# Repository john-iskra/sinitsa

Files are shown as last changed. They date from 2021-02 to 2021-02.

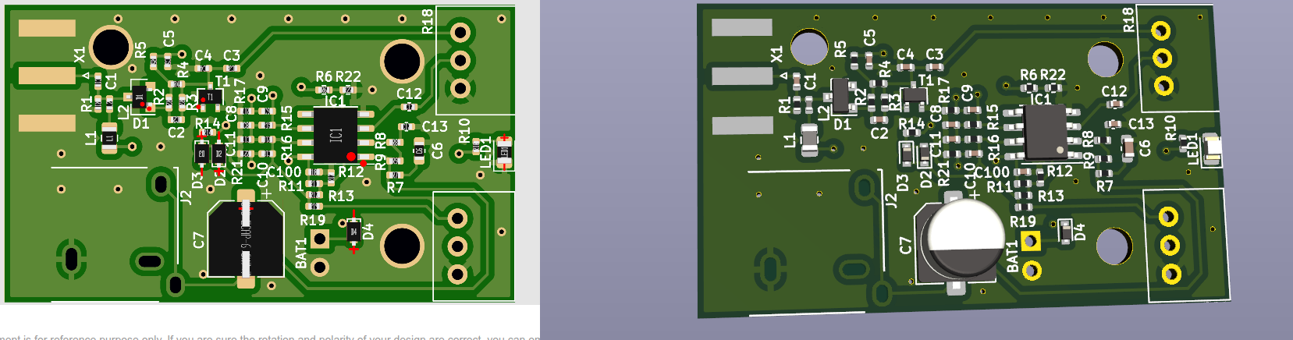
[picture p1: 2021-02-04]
preview.png

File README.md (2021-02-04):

## Sinitsa PCB Layout

Very broadband receiver, designed to pick up any radio signal in the immediate area. Useful for finding sources of interference.

Improved version of the ["Sinitsa" modification to the Amazing Allband Receiver](http://techlib.com/electronics/sinitsa.htm#Sinitsa).

This represents the diode detector section of the [original Sinitsa](https://cryptomuseum.com/df/sinitsa/index.htm). Adding filters and pre-amplifiers is left to the user.

### Ordering

Download the Gerber files from the `gerbers/` directory. Send them to your PCB manufacturer of choice.

### Parts list and assembly

The following parts need to be populated onto the board.

Once the board is populated and tested:

1. Cover the RF input section with some non-conducting tape. Then put copper or aluminum foil over top. Connect the foil to ground. This will shield the quite sensitive input section from unwanted signals in the area (cell phones, etc).
2. Use epoxy to secure the potentiometers against physical shocks. Their pins are fairly fragile.
3. Cover the whole board in heat shrink tubing. Transparent heat shrink is recommended so the power LED is visible.

|Ref |Qnty|Value |Cmp name |Footprint |Description |Vendor|
|---|----|---|---|---|---|---|
|BAT1, |1 |Battery Clip |Conn_01x02 |Connector_PinHeader_2.54mm:PinHeader_1x02_P2.54mm_Vertical  | 9V battery clip| |
|C1, |1 |100pF |C |Capacitor_SMD:C_0402_1005Metric |Unpolarized capacitor | |
|C2, C4, C5, C8, C9, C10, C11, |7 |1nF |C |Capacitor_SMD:C_0402_1005Metric |Unpolarized capacitor | |
|C3, C12, C100, |3 |100nF |C |Capacitor_SMD:C_0402_1005Metric |Unpolarized capacitor | |
|C6, |1 |47nF |C |Capacitor_SMD:C_0603_1608Metric |Unpolarized capacitor | |
|C7, |1 |220uF |C_Polarized-Device-sinitsa-rescue |Capacitor_SMD:CP_Elec_6.3x7.7 | | |
|C13, |1 |1uF |C |Capacitor_SMD:C_0402_1005Metric |Unpolarized capacitor | |
|D1, |1 |BAT17 |D_Schottky |Diode_SMD:D_SOT-23_ANK |Schottky diode | |
|D2, D3, D4, |3 |1N914WT |1N914WT |Diode_SMD:D_SOD-523 |75V 0.15A Fast switching Diode, SOD-523 | |
|IC1, |1 |LM358 |LM358 |Package_SO:SOIC-8_3.9x4.9mm_P1.27mm |Low-Power, Dual Operational Amplifiers, DIP-8/SOIC-8/TO-99-8 | |
|J2, |1 |KLBR_4 |KLBR_4-LUMBERG_3.5-sinitsa-rescue |Lumberg_3.5:Lumberg-KLBR_4-0 | | |
|L1, |1 |10uH |L |Inductor_SMD:L_0805_2012Metric |Inductor | |
|L2, |1 |39n |L |Inductor_SMD:L_0402_1005Metric |Inductor | |
|LED1, |1 |RED LED |LED |LED_SMD:LED_0805_2012Metric |Light emitting diode | |
|R1, R8, |2 |10K |R |Resistor_SMD:R_0402_1005Metric |Resistor | |
|R2, R3, |2 |10M |R |Resistor_SMD:R_0402_1005Metric |Resistor | |
|R4, R11, R12, R19, |4 |100K |R |Resistor_SMD:R_0402_1005Metric |Resistor | |
|R5, |1 |100 |R |Resistor_SMD:R_0402_1005Metric |Resistor | |
|R6, R9, R22, |3 |220K |R |Resistor_SMD:R_0402_1005Metric |Resistor | |
|R7, |1 |10 |R |Resistor_SMD:R_0402_1005Metric |Resistor | |
|R10, |1 |3k3 |R |Resistor_SMD:R_0402_1005Metric |Resistor | |
|R13, |1 |200K |R |Resistor_SMD:R_0402_1005Metric |Resistor | |
|R14, |1 |470K |R |Resistor_SMD:R_0402_1005Metric |Resistor | |
|R15, R16, R17, R21, |4 |5.1K |R |Resistor_SMD:R_0402_1005Metric |Resistor | |
|R18, |1 |10K |R_Potentiometer-Device-sinitsa-rescue|Potentiometer_THT:Potentiometer_Alps_RK097_Single_Horizontal| | |
|R20, |1 |100K |R_Potentiometer-Device-sinitsa-rescue|Potentiometer_THT:Potentiometer_Alps_RK097_Single_Horizontal| | |
|T1, |1 |MMST2222A-7-F  |BC847W |Package_TO_SOT_SMD:SOT-323_SC-70 |0.1A Ic, 45V Vce, NPN Transistor, SOT-323 | |
|X1, |1 |AMPHENOL 132289|Conn_Coaxial |Connector_Coaxial:SMA_Amphenol_132289_EdgeMount |coaxial connector | |

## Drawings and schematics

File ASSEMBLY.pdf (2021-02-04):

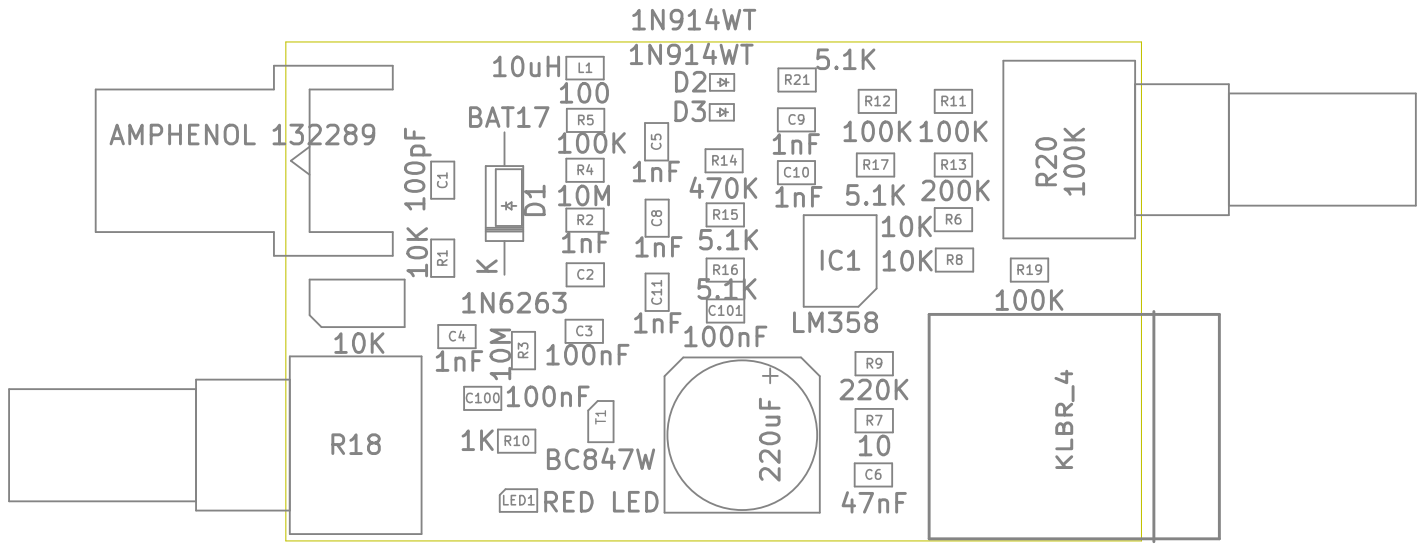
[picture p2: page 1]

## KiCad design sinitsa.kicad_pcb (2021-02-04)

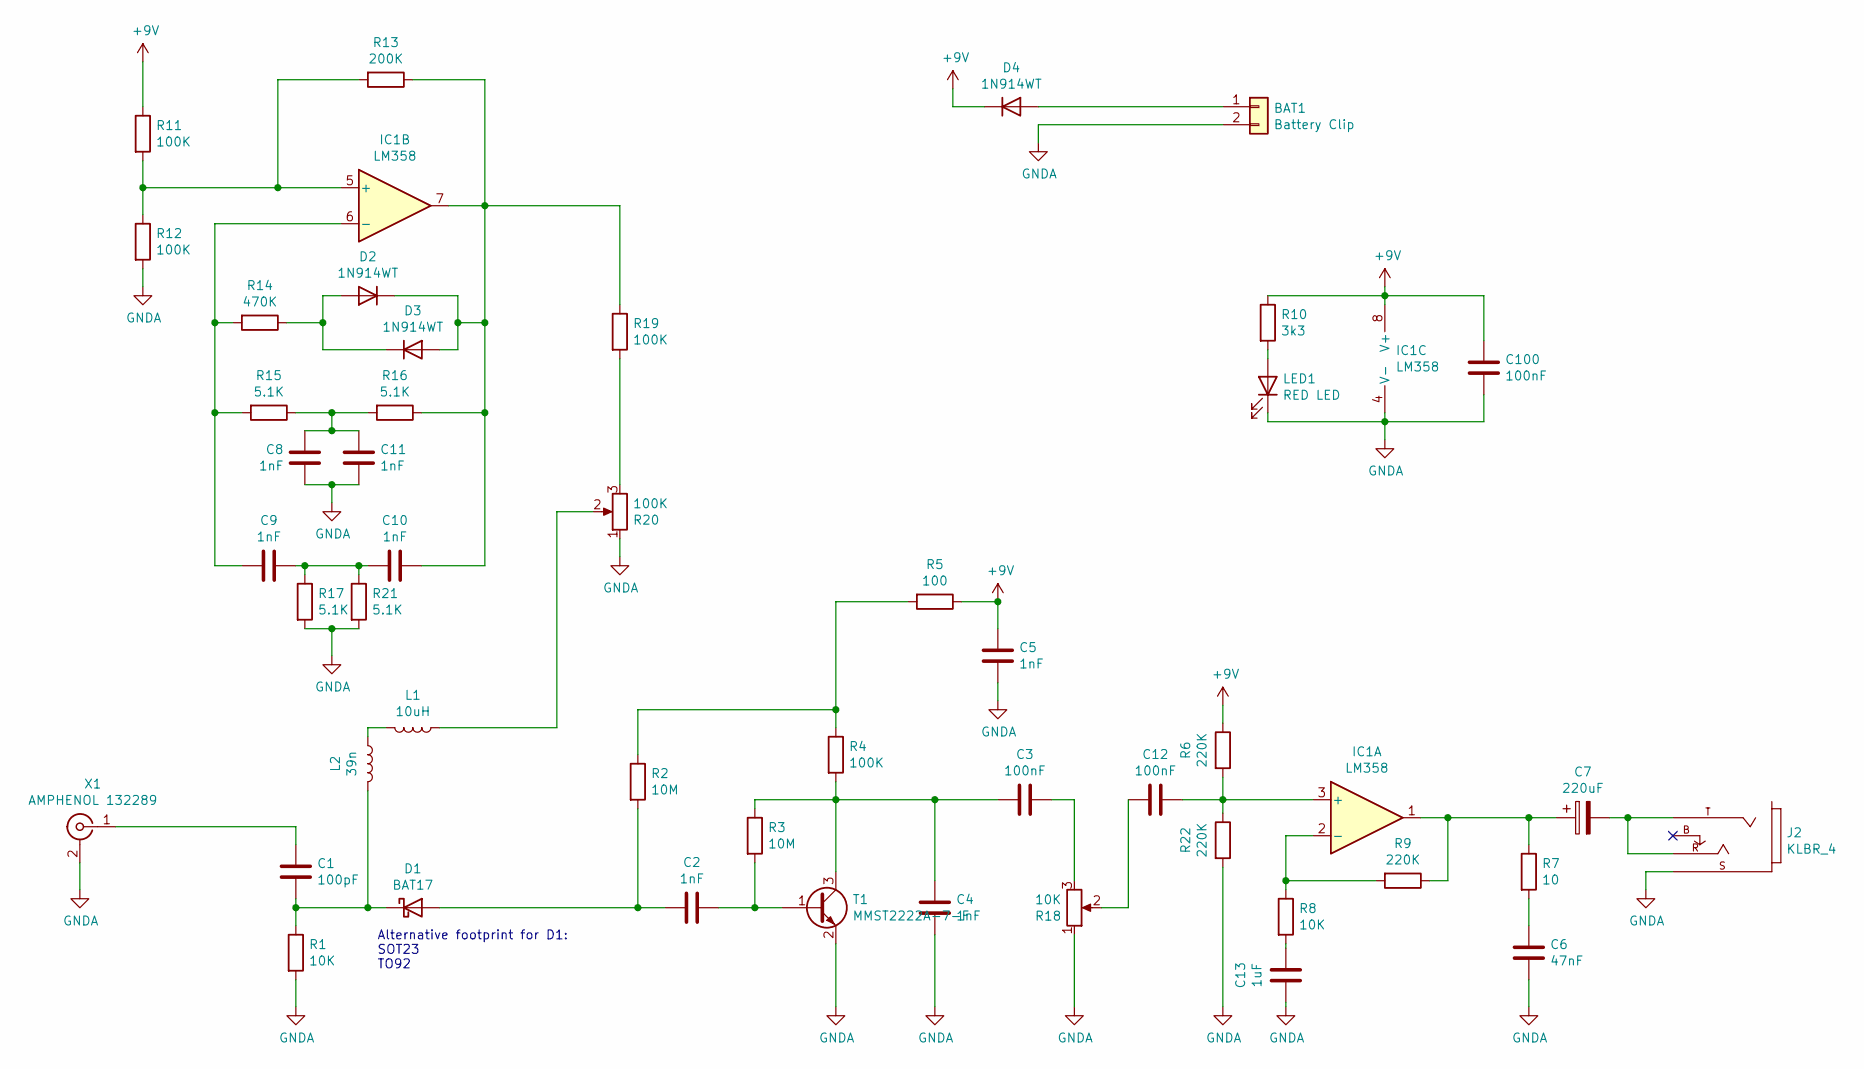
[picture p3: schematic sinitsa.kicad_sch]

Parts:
BAT1: Battery Clip; PinHeader_1x02_P2.54mm_Vertical
C1: 100pF; C_0402_1005Metric
C2, C4, C5, C8, C9, C10, C11: 1nF; C_0402_1005Metric
C3, C12, C100: 100nF; C_0402_1005Metric
C6: 47nF; C_0603_1608Metric
C7: 220uF; CP_Elec_6.3x7.7
C13: 1uF; C_0402_1005Metric
D1: BAT17; D_SOT-23_ANK
D2, D3, D4: 1N914WT; D_SOD-523
IC1: LM358; SOIC-8_3.9x4.9mm_P1.27mm
J2: KLBR_4; Lumberg-KLBR_4-0
L1: 10uH; L_0805_2012Metric
L2: 39n; L_0402_1005Metric
LED1: RED LED; LED_0805_2012Metric
R1, R8: 10K; R_0402_1005Metric
R2, R3: 10M; R_0402_1005Metric
R4, R11, R12, R19: 100K; R_0402_1005Metric
R5: 100; R_0402_1005Metric
R6, R9, R22: 220K; R_0402_1005Metric
R7: 10; R_0402_1005Metric
R10: 3k3; R_0402_1005Metric
R13: 200K; R_0402_1005Metric
R14: 470K; R_0402_1005Metric
R15, R16, R17, R21: 5.1K; R_0402_1005Metric
R18: 10K; Potentiometer_Alps_RK097_Single_Horizontal
R20: 100K; Potentiometer_Alps_RK097_Single_Horizontal
T1: MMST2222A-7-F; SOT-323_SC-70
X1: AMPHENOL 132289; SMA_Amphenol_132289_EdgeMount

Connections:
+9V: C5.1, C100.1, D4.1 (K), IC1.8 (V+), R5.1, R6.1, R10.1, R11.1
GNDA: BAT1.2, C4.2, C5.2, C6.2, C8.1, C11.2, C13.2, C100.2, IC1.4 (V-), J2.S, LED1.1 (K), R1.2, R12.2, R17.2, R18.1, R20.1, R21.2, R22.2, T1.2 (E), X1.2 (Ext)
unnamed: BAT1.1, D4.2 (A)
unnamed: C1.1, X1.1 (In)
unnamed: C1.2, D1.1 (K), L2.2, R1.1
unnamed: C2.1, R3.2, T1.1 (B)
unnamed: C2.2, D1.2 (A), R2.2
unnamed: C3.1, R18.3
unnamed: C3.2, C4.1, R3.1, R4.2, T1.3 (C)
unnamed: C6.1, R7.2
unnamed: C7.1, IC1.1, R7.1, R9.1
unnamed: C7.2, J2.R, J2.T
unnamed: C9.2, IC1.6 (-), R14.2, R15.2
unnamed: C10.1, D2.1 (K), D3.2 (A), IC1.7, R13.1, R16.1, R19.1
unnamed: C9.1, C10.2, R17.1, R21.1
unnamed: C8.2, C11.1, R15.1, R16.2
unnamed: D2.2 (A), D3.1 (K), R14.1
unnamed: IC1.2 (-), R8.1, R9.2
unnamed: C12.1, IC1.3 (+), R6.2, R22.1
unnamed: IC1.5 (+), R11.2, R12.1, R13.2
unnamed: L1.1, R20.2
unnamed: L1.2, L2.1
unnamed: LED1.2 (A), R10.2
unnamed: R2.1, R4.1, R5.2
unnamed: C13.1, R8.2
unnamed: C12.2, R18.2
unnamed: R19.2, R20.3

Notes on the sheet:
Alternative footprint for D1: SOT23 TO92

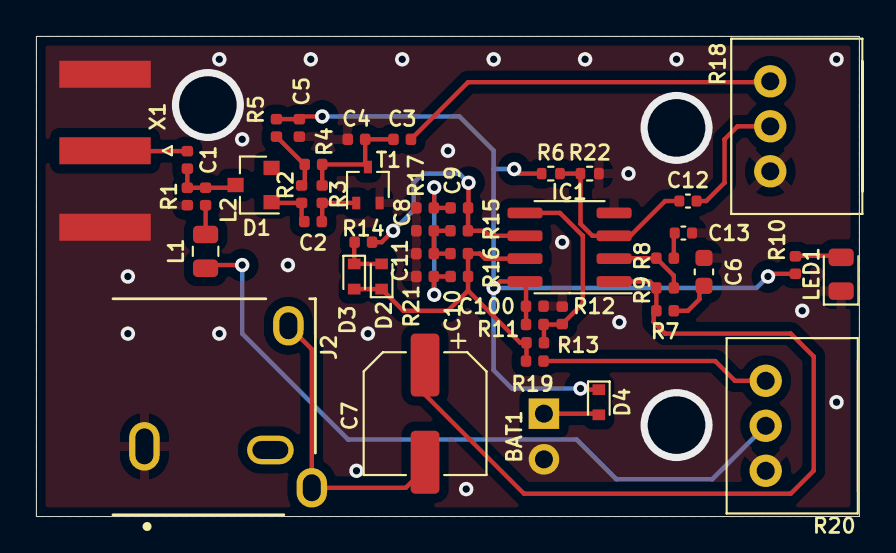
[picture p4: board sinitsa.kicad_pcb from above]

Board: 2 copper layers, 45.7 x 26.7 mm, 48 parts (0 on the bottom side), 27 nets.
